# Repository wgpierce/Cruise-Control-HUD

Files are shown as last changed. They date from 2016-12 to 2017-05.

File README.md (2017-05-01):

# Cruise-Control-HUD
Cruise control HUD MiniProject for ECE 362 and Purdue Spark Challenge

## Setup

Configuration and project files have been omitted since they carry no useful information
and are a pain to track

If you do want to use this code yourself, using CodeWarrior, do the following:

Open CodeWarrior, and navigate through these generic dialogs.
The setting we used are right below the corresponding generic tag.

File -> New Project -> \<family\> -> \<specific member\> -> \<whichever connections\> -> Next -> Finish                  
&nbsp;&nbsp;&nbsp;&nbsp;&nbsp;&nbsp;&nbsp;&nbsp;&nbsp;&nbsp;&nbsp;&nbsp;&nbsp;&nbsp;&nbsp;&nbsp;&nbsp;&nbsp;&nbsp;&nbsp;&nbsp;&nbsp;&nbsp;&nbsp;&nbsp;&nbsp; HCS12C FAMILY &nbsp;&nbsp;&nbsp;&nbsp; MC9S12C32 &nbsp;&nbsp;&nbsp;&nbsp;&nbsp;&nbsp;&nbsp;&nbsp;&nbsp;&nbsp;&nbsp;&nbsp;&nbsp;&nbsp;&nbsp;&nbsp;&nbsp;&nbsp; USB BDM Multilink 

After that, you can just copy the code from the main.c file in this repository to replace the main.c in 
your projectFolder/Sources/ folder
		
## Technologies used

#### Hardware
- MC9S12C32 microcontroller board
- OBD to UART Cable
- LIDAR
- Custom PCB with power wired to OBD board
- Shift Registers
- 4x7-segment Displays
- Printrbot Simple Metal

#### Software
- CodeWarrior
	- USBMLT
- Eagle
- Autodesk Fusion

See Documentation for more specific details

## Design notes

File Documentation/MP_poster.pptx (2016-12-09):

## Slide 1

ECE 362 Embedded Microcontroller Mini-Project - Fall 2016
Team 01 – Cruise Control HUD

“The HUD that will help your BFFAM improve his driving skills”

https://youtu.be/xGuQt2sF4p8

Overview
Cruise control HUD aims to help drivers by dynamically displaying data about the car’s velocity, distance to oncoming cars, and whether to slow down or speed up.

On-Chip Peripherals Detail
This project uses the ATD to receive a PWM signal from the LIDAR, the TIM module to control LED refresh rates and LIDAR sampling, the SCI to communicate with the car, and the SPI module to drive 7-segments through a shift register.

Team Members: Patrick May, Will Pierce, Tyler Carter

Implementation
This project obtains its speed measurement by continuously polling a speed reading via SCI from the Engine Control Unit (ECU) of a car through the OBD port. Distance measurements are obtained by triggering a distance measurement on the LIDAR and then reading the value the LIDAR responds with using and ATD to calculate how long the pulse is and converting that to a distance. These inputs are then shifted out via SPI to external shift registers which drive 7-segment LEDs.

Additional Circuitry
The main board interfaces to a MAX232 mounted on a perfboard. This is then interfaced to a Sparkfun OBD-to-UART board.

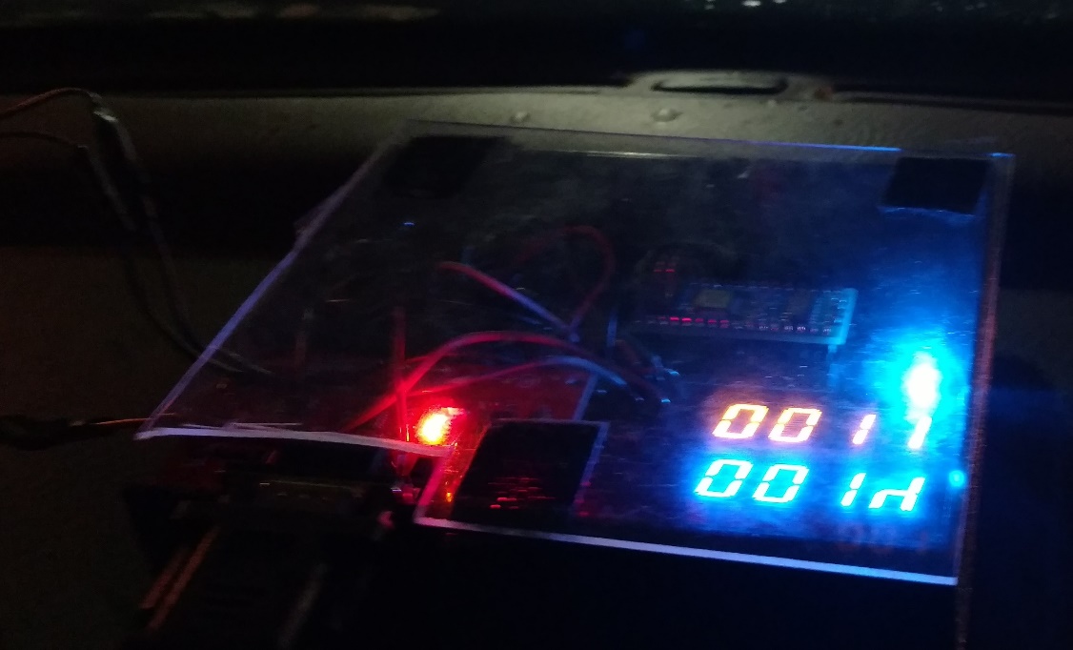
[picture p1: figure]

Project in Operation

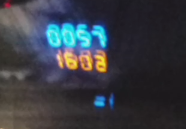
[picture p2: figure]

The displays reflecting off the windshield

LIDAR

SCI

OBD-to-TTL converter

Digijock(ette)-Strength Digital System DesignTM

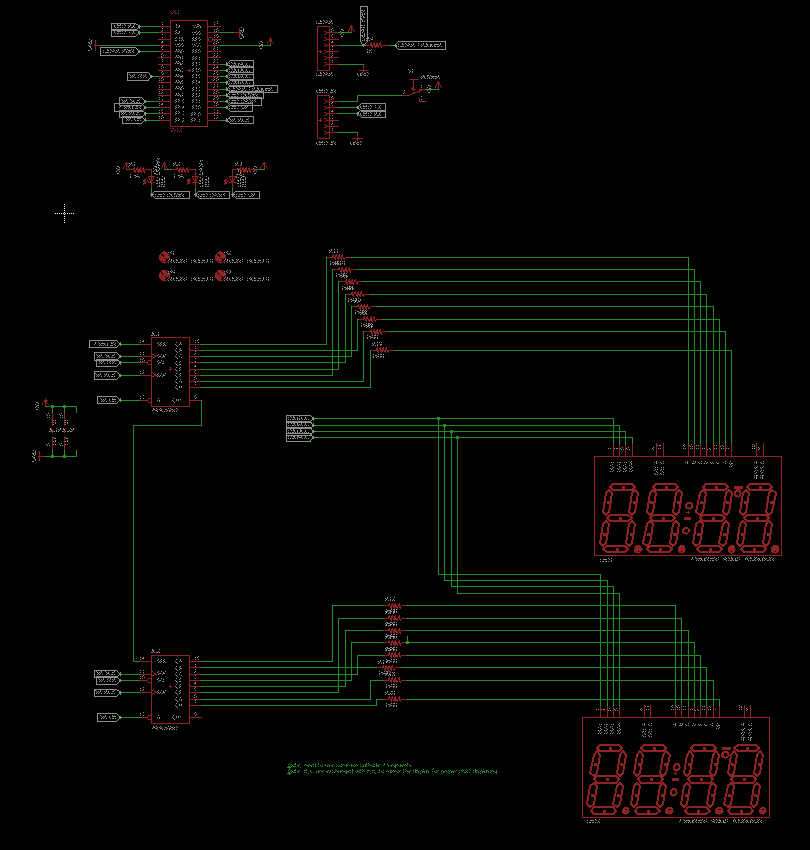
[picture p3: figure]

Circuit Schematic

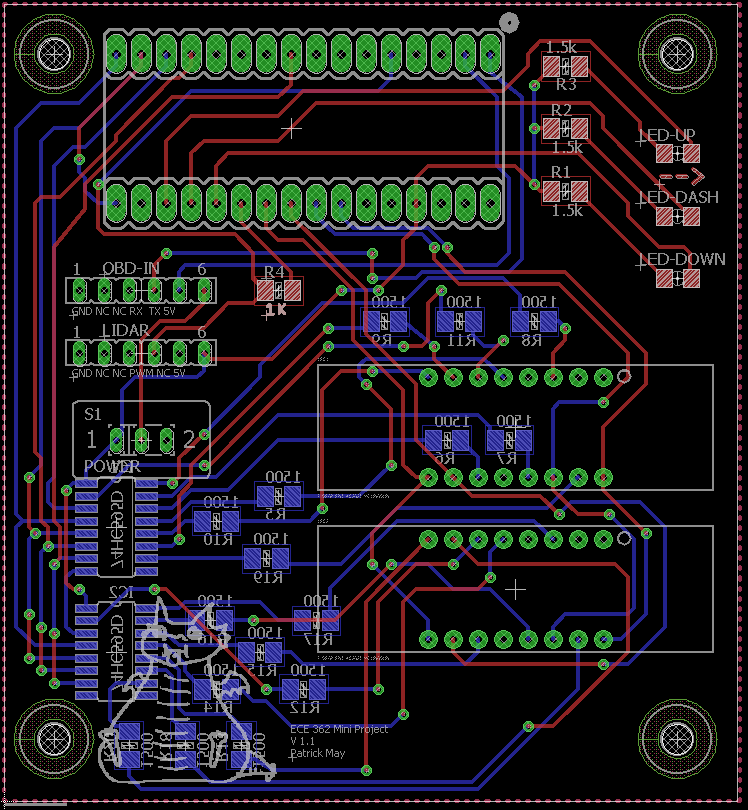
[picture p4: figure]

Board layout

ATD

PWM

Speed up/
Slow down LEDs

Future Work
For future work, we consider consolidating all circuitry to a single board and using solderless connectors to “foolproof” the design.

9S12C

SPI

Shift Registers

7 Segment Displays

Additional Design Work
The PCB was created in Eagle and produced at OSHPark. 3D-printed enclosures for both the LIDAR and boards were designed using Autodesk Fusion and printed on a Printrbot Simple Metal. The LIDAR is attached to the hood of a car using neodymium magnets

Car

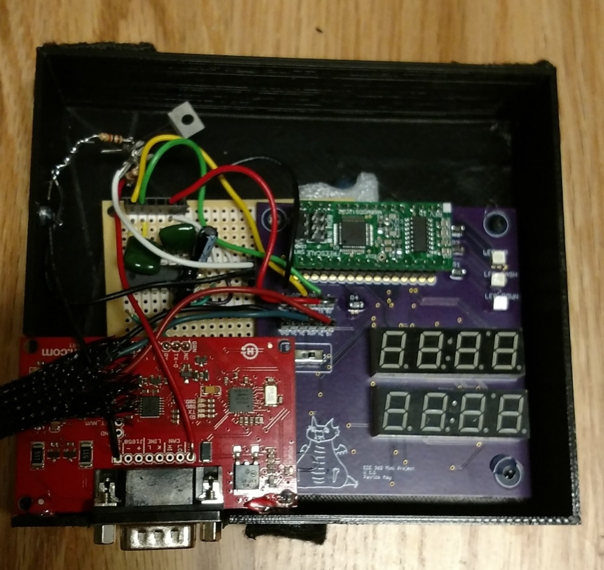
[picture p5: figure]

All boards inside enclosure

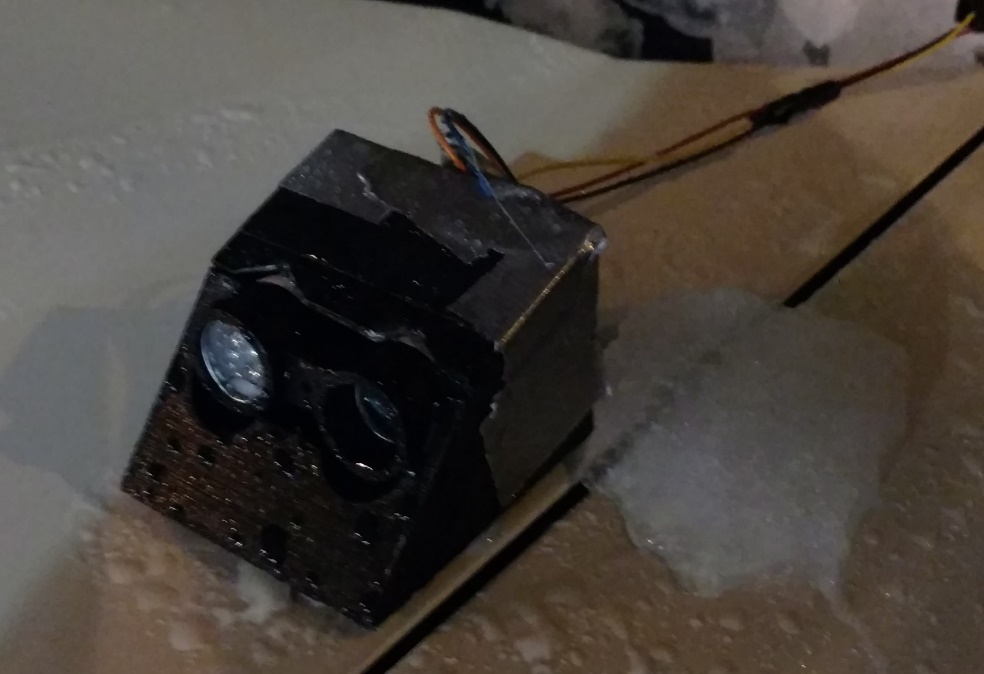
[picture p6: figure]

LIDAR in its enclosure attached to a car

OBD Port

Power

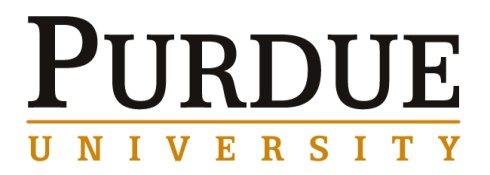
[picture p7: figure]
PU_signature_jpg_print

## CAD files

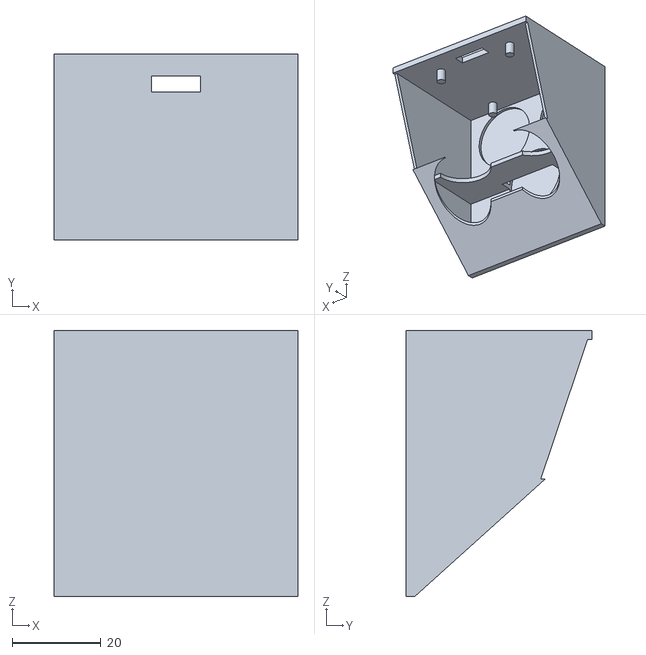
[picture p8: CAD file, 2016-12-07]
3D Printer Files/LIDAR Enclosure/LIDAR Enclosure.stl
55.0 x 42.0 x 60.0

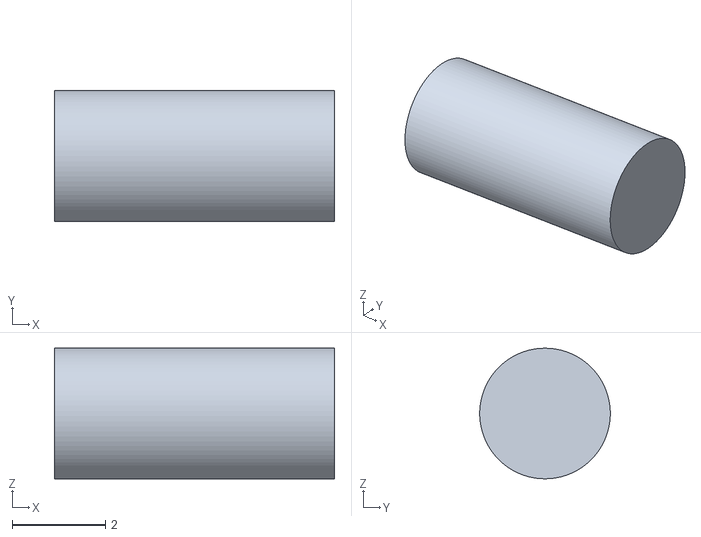
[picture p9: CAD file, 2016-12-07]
3D Printer Files/LIDAR Enclosure/LIDAR peg.stl
6.00 x 2.80 x 2.80

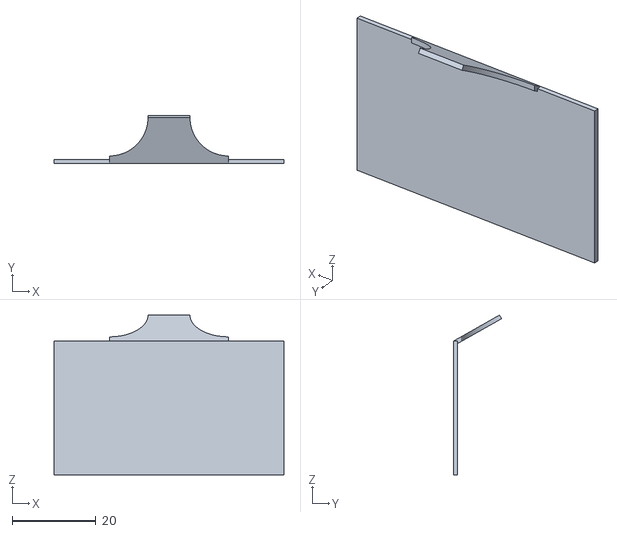
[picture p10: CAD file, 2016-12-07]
3D Printer Files/LIDAR Enclosure/LIDAR Enclosure Lid.stl
55.0 x 11.5 x 38.2

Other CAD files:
3D Printer Files/LIDAR Enclosure/LIDAR Enclosure Lid v2.f3d
3D Printer Files/LIDAR Enclosure/LIDAR Enclosure v2.f3d
3D Printer Files/LIDAR Enclosure/LIDAR Peg v1.f3d
3D Printer Files/PCB Enclosure/ECE362MiniProj.f3d

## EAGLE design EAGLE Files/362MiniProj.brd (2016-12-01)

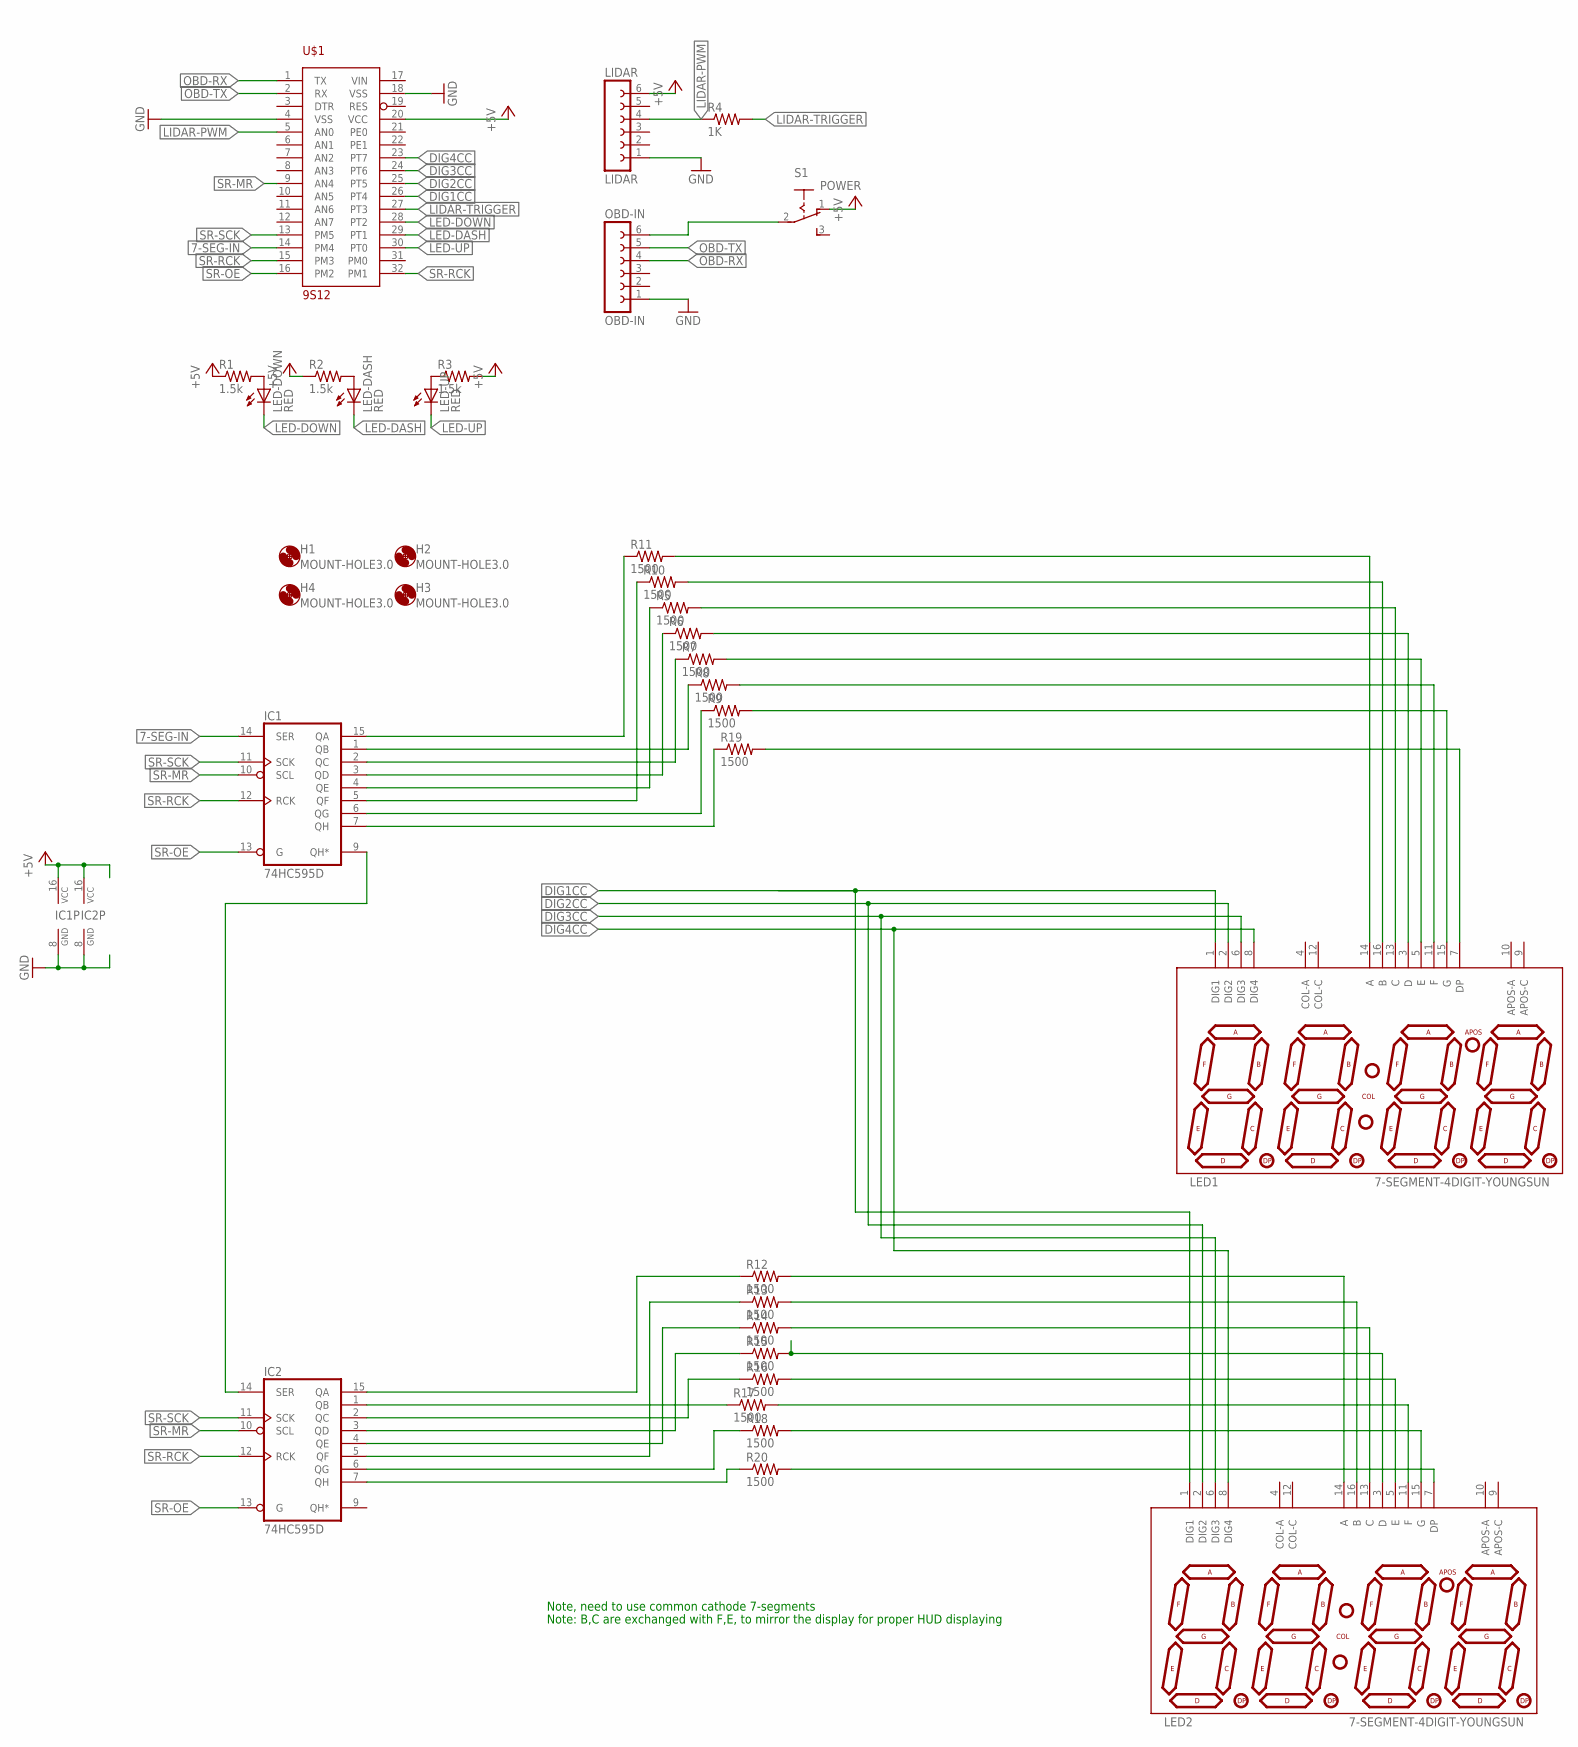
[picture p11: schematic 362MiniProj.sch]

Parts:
H1, H2, H3, H4: MOUNT-HOLE3.0; 3,0
IC1, IC2: 74HC595D; SO16
LED1, LED2: 7-SEGMENT-4DIGIT-YOUNGSUN
LED-DASH: RED; LED_1206
LED-DOWN: RED; LED_1206
LED-UP: RED; LED_1206
LIDAR: LIDAR; FE06
OBD-IN: OBD-IN; FE06
R1, R2, R3: 1.5k; M1206
R4: 1K; M1206
R5, R6, R7, R8, R9, R10, R11, R12, R13, R14, R15, R16, R17, R18, R19, R20: 1500; M1206
S1: POWER; M251
U$1: 9S12; DIP-32

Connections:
7-SEG-IN: IC1.14 (SER), U$1.14 (PM4)
+5V: IC1.16 (VCC), IC2.16 (VCC), LIDAR.6, R1.1, R2.1, R3.2, S1.1 (O), U$1.20 (VCC)
DIG1CC: LED1.1 (DIG1), LED2.1 (DIG1), U$1.26 (PT4)
DIG2CC: LED1.2 (DIG2), LED2.2 (DIG2), U$1.25 (PT5)
DIG3CC: LED1.6 (DIG3), LED2.6 (DIG3), U$1.24 (PT6)
DIG4CC: LED1.8 (DIG4), LED2.8 (DIG4), U$1.23 (PT7)
GND: IC1.8 (GND), IC2.8 (GND), LIDAR.1, OBD-IN.1, U$1.4 (VSS), U$1.18 (VSS)
LED-DASH: LED-DASH.C, U$1.29 (PT1)
LED-DOWN: LED-DOWN.C, U$1.28 (PT2)
LED-UP: LED-UP.C, U$1.30 (PT0)
LIDAR-PWM: LIDAR.4, R4.1, U$1.5 (AN0)
LIDAR-TRIGGER: R4.2, U$1.27 (PT3)
unnamed: IC1.9 (QH*), IC2.14 (SER)
unnamed: LED-DOWN.A, R1.2
unnamed: LED-DASH.A, R2.2
unnamed: LED-UP.A, R3.1
unnamed: IC1.15 (QA), R11.1
unnamed: IC1.1 (QB), R8.1
unnamed: IC1.2 (QC), R7.1
unnamed: IC1.4 (QE), R5.1
unnamed: IC1.3 (QD), R6.1
unnamed: IC1.5 (QF), R10.1
unnamed: IC1.6 (QG), R9.1
unnamed: IC1.7 (QH), R19.1
unnamed: IC2.7 (QH), R20.1
unnamed: LED1.14 (A), R11.2
unnamed: OBD-IN.6, S1.2
unnamed: LED2.3 (D), R15.2
unnamed: LED1.16 (B), R10.2
unnamed: LED1.13 (C), R5.2
unnamed: LED1.3 (D), R6.2
unnamed: LED1.5 (E), R7.2
unnamed: LED1.11 (F), R8.2
unnamed: LED1.15 (G), R9.2
unnamed: IC2.15 (QA), R12.1
unnamed: IC2.5 (QF), R13.1
unnamed: IC2.4 (QE), R14.1
unnamed: IC2.3 (QD), R15.1
unnamed: IC2.2 (QC), R16.1
unnamed: IC2.1 (QB), R17.1
unnamed: IC2.6 (QG), R18.1
unnamed: LED1.7 (DP), R19.2
unnamed: LED2.14 (A), R12.2
unnamed: LED2.16 (B), R13.2
unnamed: LED2.13 (C), R14.2
unnamed: LED2.5 (E), R16.2
unnamed: LED2.11 (F), R17.2
unnamed: LED2.15 (G), R18.2
unnamed: LED2.7 (DP), R20.2
OBD-RX: OBD-IN.4, U$1.1 (TX)
OBD-TX: OBD-IN.5, U$1.2 (RX)
SR-MR: IC1.10 (SCL), IC2.10 (SCL), U$1.9 (AN4)
SR-OE: IC1.13 (G), IC2.13 (G), U$1.16 (PM2)
SR-RCK: IC1.12 (RCK), IC2.12 (RCK), U$1.15 (PM3), U$1.32 (PM1)
SR-SCK: IC1.11 (SCK), IC2.11 (SCK), U$1.13 (PM5)

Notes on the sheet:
Note, need to use common cathode 7-segments
Note: B,C are exchanged with F,E, to mirror the display for proper HUD displaying

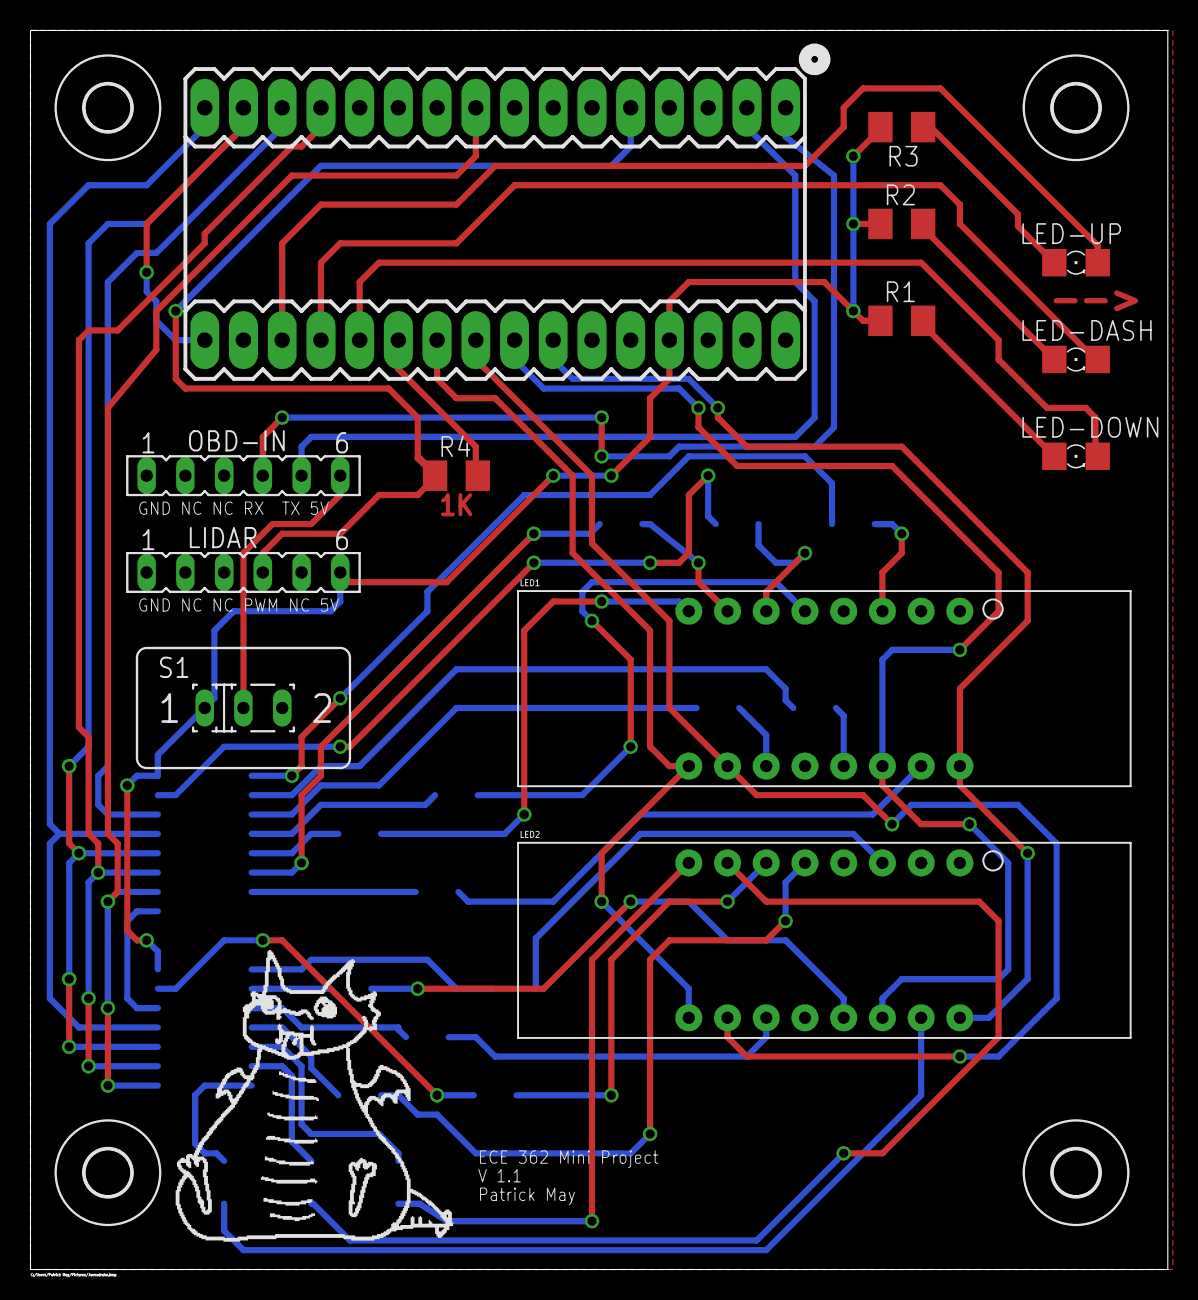
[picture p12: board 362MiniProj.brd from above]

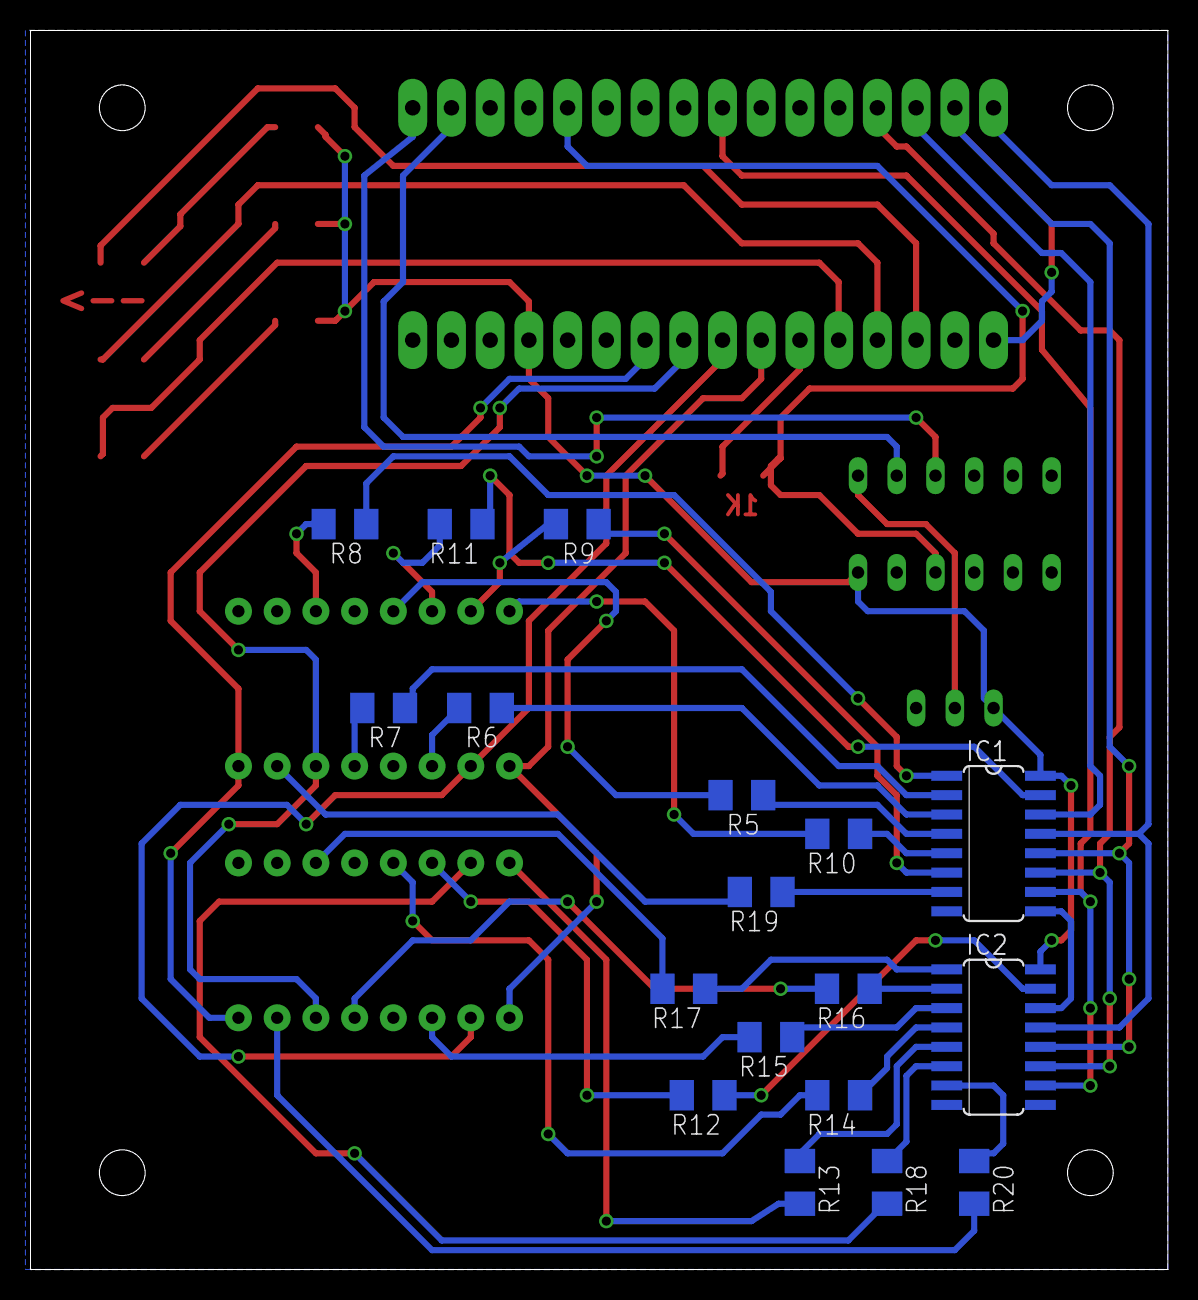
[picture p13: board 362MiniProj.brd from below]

Board: 2 copper layers, 74.6 x 81.3 mm, 35 parts (18 on the bottom side), 55 nets.

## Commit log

2016-11-12 Fixed formatting, set coding standard, wrote shift register driver
2016-11-14 finished multidigit operation and adjusted timing parameters for LED driver
2016-11-21 modified LED driver so it doesn't take up processing time, wrote rudimentary LIDAR driver
2016-11-22 Started OBD board drivers
2016-11-30 fixed many port declarations tested LED up/down/dash disable MISO in SPI for use as GPIO pin set slave select as input to prevent shorting double-buffer LEDs (shift out 2 digits at a time) reverse di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
2016-12-01 Added EAGLE files
    [362MiniProj.brd, 362MiniProj.sch]
2016-12-02 rewrote LIDAR driver to work now LIDAR is now based on ATD interrupts to measure for a set period of time
2016-12-02 removed dedicated LIDAR functions
2016-12-03 changed LIDAR to only take masurement when we read measurement
2016-12-04 Fixed LIDAR bug, changed display orientation
2016-12-06 Fixed LIDAR drivers
2016-12-07 wrote more on PPT and readme
    [LIDAR Enclosure Lid v2.f3d, LIDAR Enclosure Lid.stl, LIDAR Enclosure v2.f3d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]
2016-12-09 Added Enclosure
    [ECE362MiniProj.f3d]

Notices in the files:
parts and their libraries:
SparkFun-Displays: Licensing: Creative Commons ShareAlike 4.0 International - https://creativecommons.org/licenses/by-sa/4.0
